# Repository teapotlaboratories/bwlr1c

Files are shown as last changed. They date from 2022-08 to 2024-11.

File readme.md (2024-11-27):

  
# Teapotlabs BWLR1C
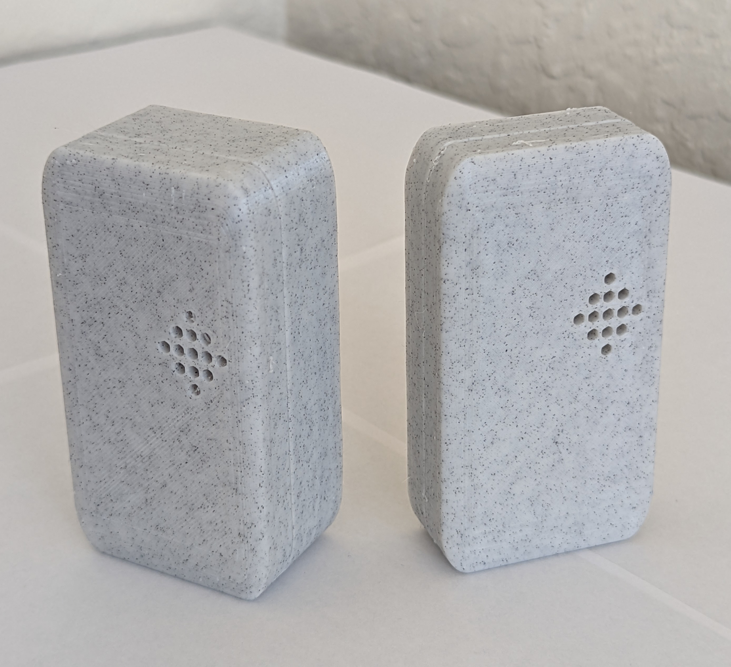
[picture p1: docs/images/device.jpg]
 
 
Teapotlabs BWLR1C is a wireless LoRa environmental sensor capable of sensing temperature, humidity, air pressure and air quality using the on-board BME680.
This device is an updated to **Teapotlabs BWLR1B,** by using the an on-board antenna.
By using an STM32WLE MCU, the device is capable of multi-year operation before changing the batteries

Teapotlabs BWLR1C is part of  [Teapot open-hardware project](https://github.com/teapotlaboratories).

## Sponsorship
Huge thanks to [PCBWay](https://www.pcbway.com/) to sponsored this project! Most of the project in Teapotlabs from PCB board, PCB Assembly, and 3D Printing is done through their rapid-prototyping services. The process from ordering to delivery of the device was really smooth and easy. We were really happy with the quality of the assembly and especially the customer support that was really easy to work with, where they help us identify and fix issue such as verifying BOM, checking components for assembly and even replacing damaged parts at no cost.

## Disclaimer
- The 1KM range is based on [AERQ - Air Quality Monitoring](https://www.seeedstudio.com/blog/2022/04/27/monitoring-indoor-air-pollutants-the-silent-issue-for-smart-city-iot-using-seeed-lora-e5-and-fusion-pcba/) design, but have not been tested on this device yet
- The position of the BME680 sensor on the board might not be the most efficient

## Future Works
- Change `SW4` wiring from GND to 3V3, to allow booting to STM32WLE USART Bootloader. This enable the user to flash the RAK3172 module using STM32CubeProgrammer without ST-Link.

## Specification

- [RAK3172](https://docs.rakwireless.com/Product-Categories/WisDuo/RAK3172-Module/Overview/): An STM32WLE5CC module
- 3.3V only power/pin. 
- 2uA Deep-Sleep
- BME680 for Environmental Sensing
- Switchable TX Power. 14 dBm(50mA) or 22 dBm(140mA) ( on 915MHz frequency )
- Supports LoRaWAN 1.0.3
- 1KM Range
- UART2 breakout for **Arduino** progamming
- SWD breakout for **Mbed OS/STM32Cube** programming
- SMA antenna connector
- **CR2450** battery holder *xor* **AA** battery holder
- Capacitor ( [optional to prolong CR2450 usage](https://www.rs-online.com/designspark/can-i-prolong-my-coin-cell-battery-life-with-a-capacitor) )

> Based-on [TI's White Paper](https://www.ti.com/lit/wp/swra349/swra349.pdf), using coin-cell to draw short high-power pulses (~40mA) is possible, but will reduce the effective capacity of the battery. The White Paper proposed a solution to increase the effective capacity
## Schematics

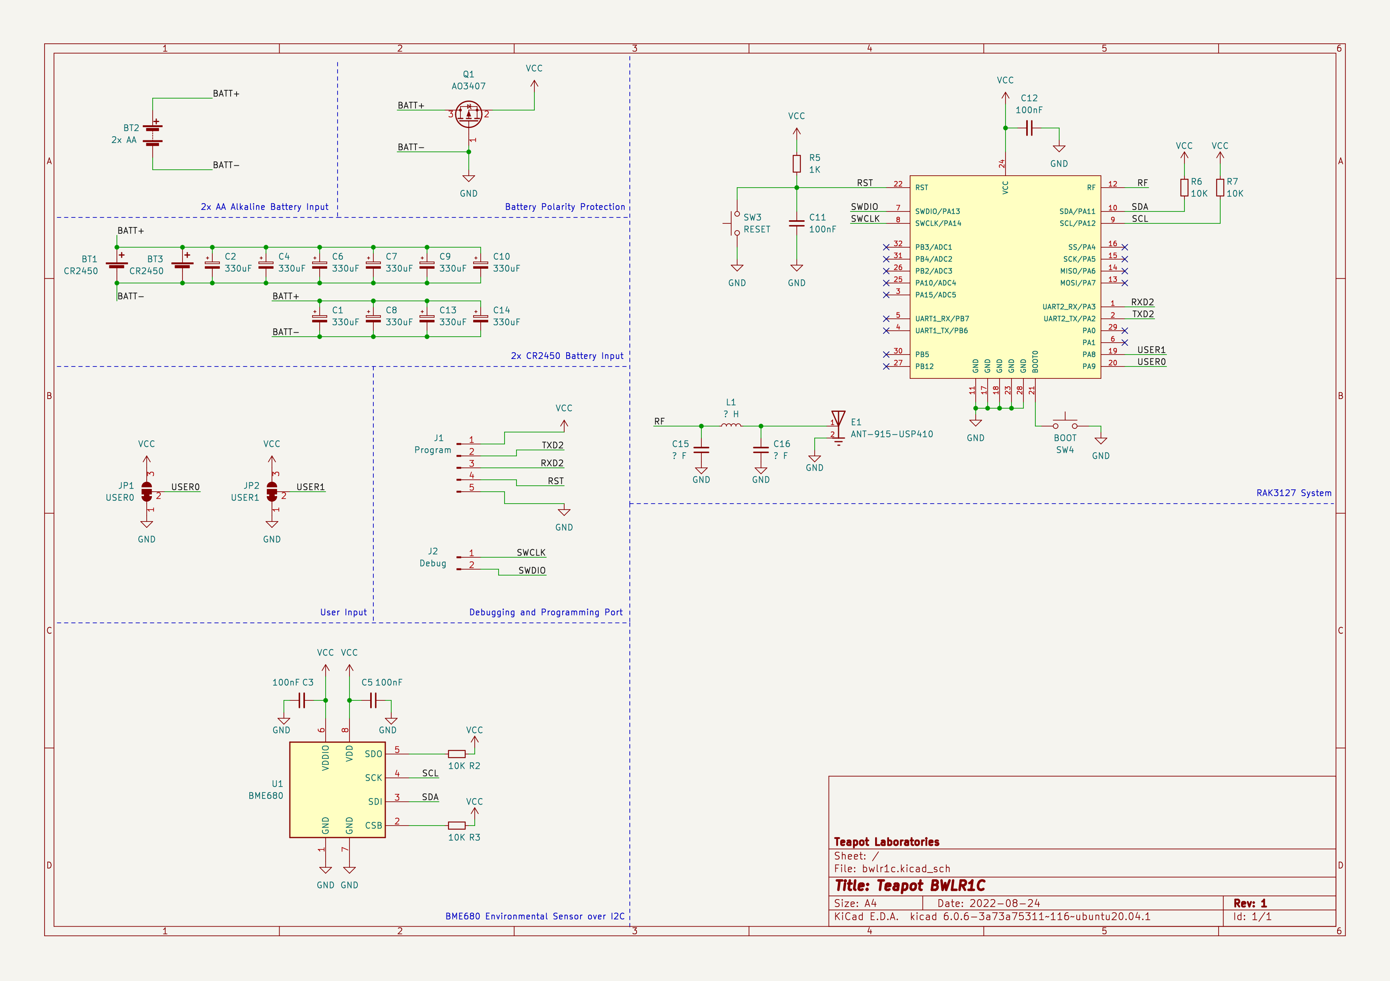
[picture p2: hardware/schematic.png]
schematic


## Boards
 <p align="center">  pcb_render<br><b>PCB Render</b></p>

Built using KiCAD, the board is design to be as small as possible when operated using CR2450 coin-cell batteries

| Top Board | Bottom Board |
|--|--|
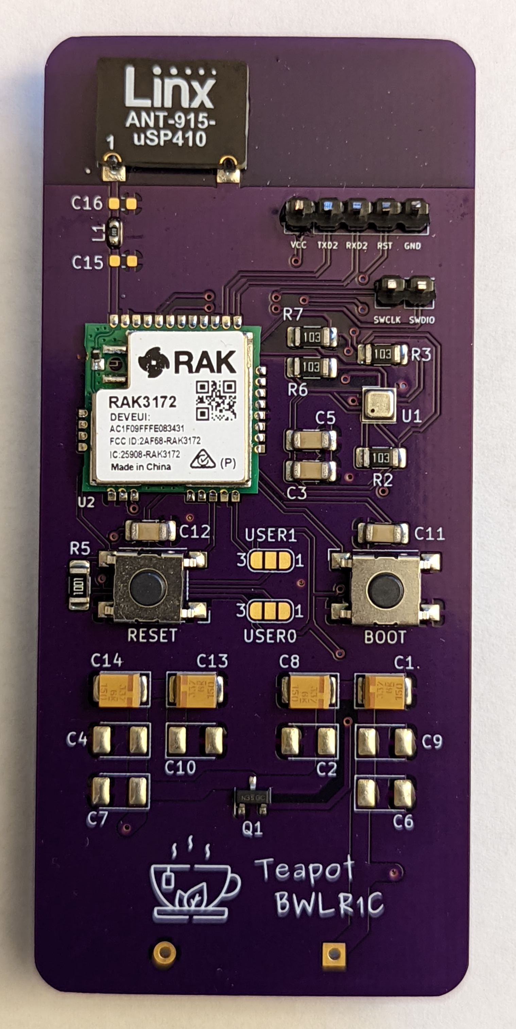
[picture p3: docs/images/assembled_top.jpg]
assembled_front
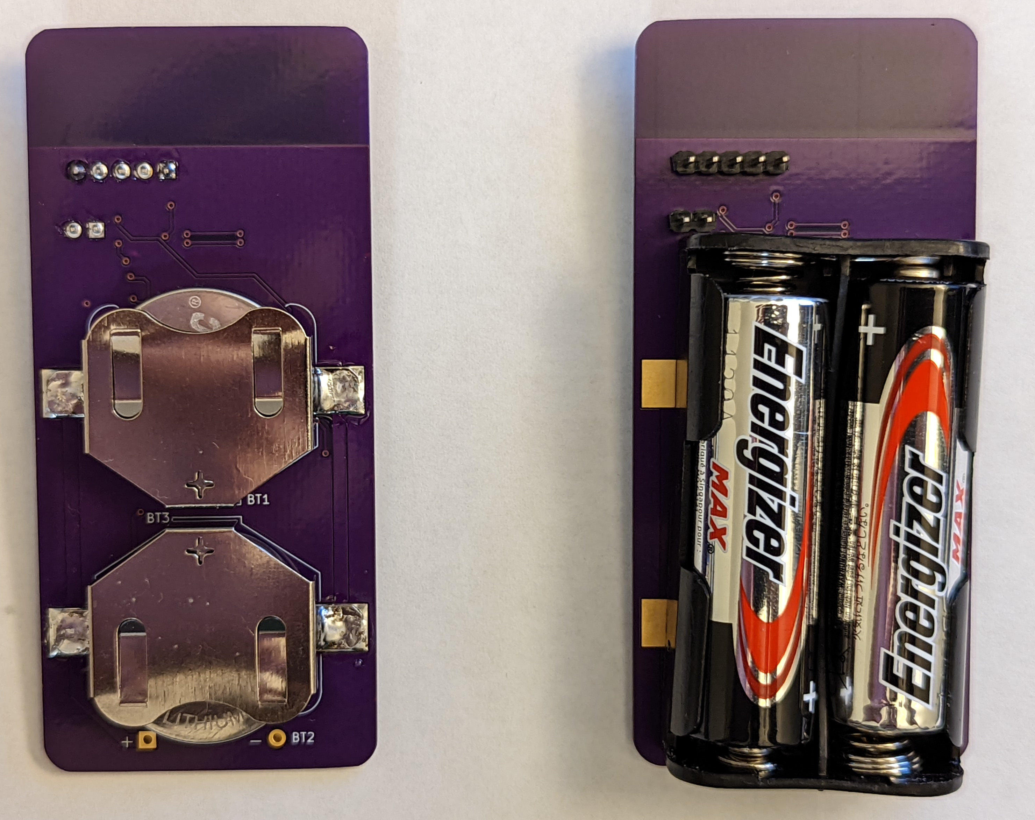
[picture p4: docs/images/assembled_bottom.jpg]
assembled_back
|  |  |
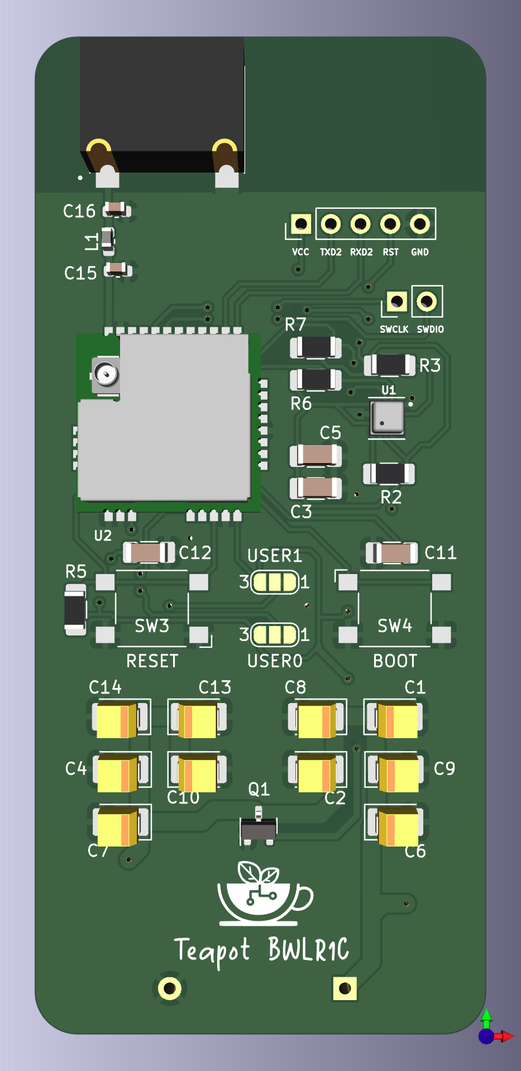
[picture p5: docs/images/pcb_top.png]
pcb_front
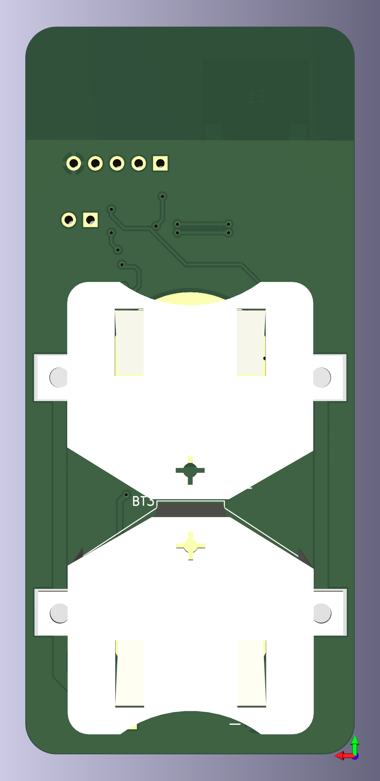
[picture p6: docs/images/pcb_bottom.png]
pcb_bottom
|  |  |

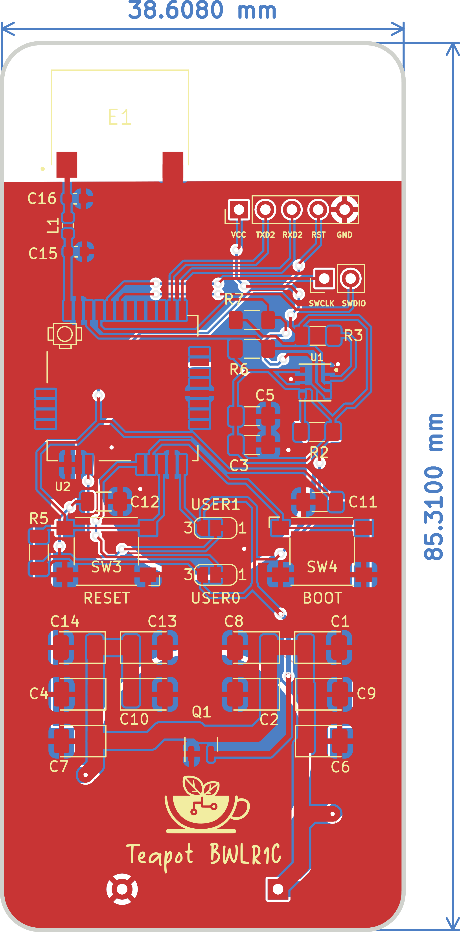
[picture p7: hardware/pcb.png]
pcb
 <p align="center"> <br><b>PCB Top and Bottom Layout</b></p> 
  
### Case
<p align="center">  case_render</p>

Built using [TinkerCAD](https://www.tinkercad.com), the cases are available for the CR2450 variant and the AA variant, 3D printable with any generic 3D printer with/without suppport (depends on the orientation). The STL files are available [here](https://github.com/teapotlaboratories/bwlr1c/tree/main/hardware/case)
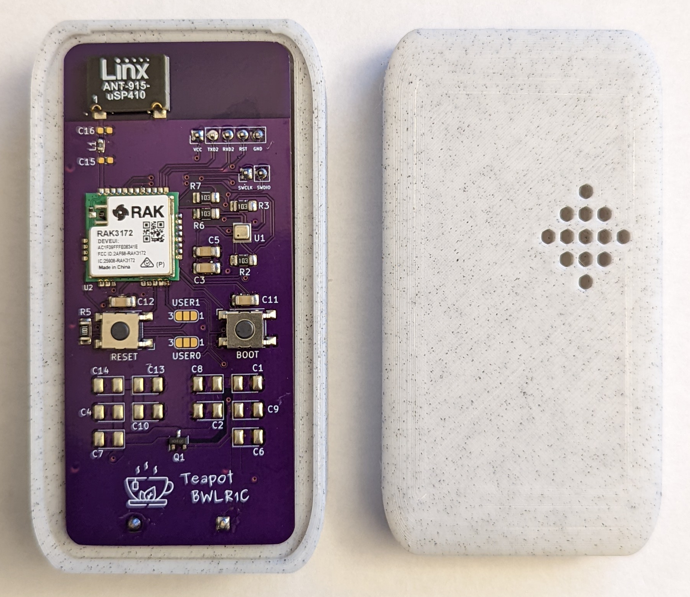
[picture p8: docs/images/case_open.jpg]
 <p align="center"><br><b>Case Open</b></p>

The case is design to be as small as possible with an additional magnets in the back to ease the placement of the sensor. The following are the list of material used at the time of testing:
- 4 piece of 8mm x 2mm neodymium magnet

<p align="center">placement_showcase<br><b>Sensor Placement with Magnet</b></p>

### Measurement
Power consumption and solar charging current are measured using [Nordic PPK2](https://www.nordicsemi.com/Products/Development-hardware/Power-Profiler-Kit-2).
The following are the summary of the measurement:
- Transmit 14dBm:  443ms @ 47mA
- Deep-Sleep : 2 uA

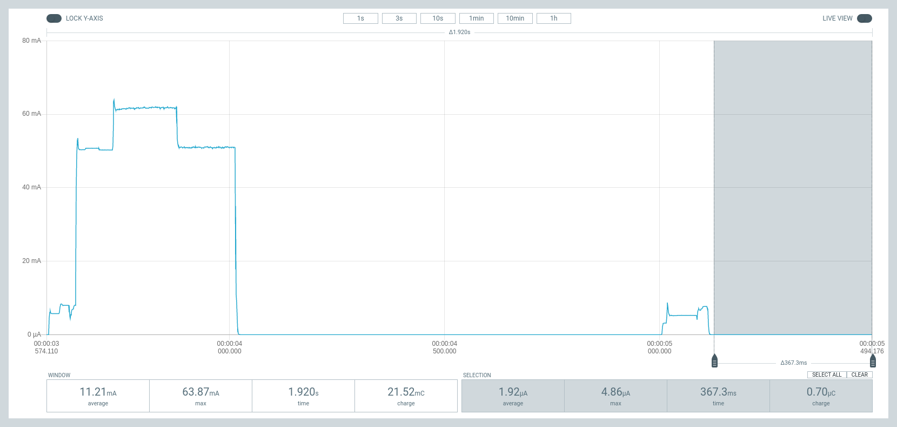
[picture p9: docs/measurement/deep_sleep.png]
deep_sleep
<p align="center"><br><b>Deep-Sleep</b></p>

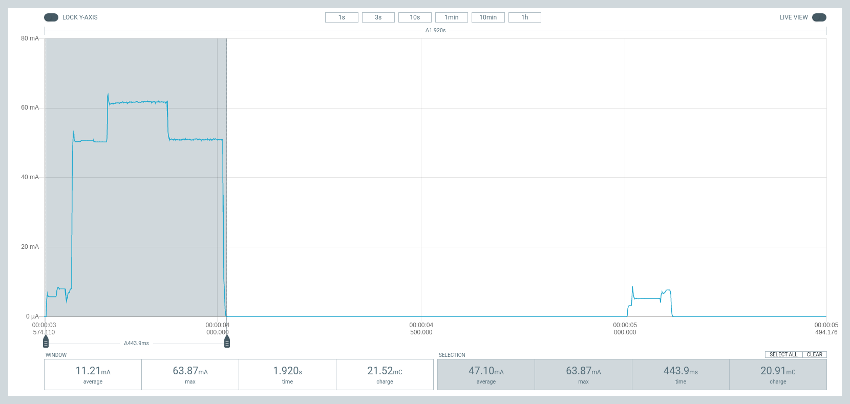
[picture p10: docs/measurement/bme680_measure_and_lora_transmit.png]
bme688_measure_and_lora_transmit
<p align="center"><br><b>BME688 Measure and LoRa Transmit</b></p>

More measurement can be found [here](https://github.com/teapotlaboratories/bwlr1c/tree/main/docs/measurement)

### Bill Of Materials
Most of the components are generic and can be bought from any electornics/semi-conductor distributor. RAK3172 is the only component available in [RAKwireless store](https://store.rakwireless.com/products/wisduo-lpwan-module-rak3172?variant=40014759493830). The bill of materials can be downloaded [here](https://github.com/teapotlaboratories/bwlr1c/raw/main/hardware/bill_of_materials.csv)

> :warning: **Be sure to buy the RAK3172 variant without IPEX to use the On-Board Antenna** 

|Id |Designator |Package |Quantity|Designation |Notes |
|---|---|---|---|---|---|
|1  |C5,C12,C11,C3 |C_1206_3216Metric |4 |100nF | |
|2  |SW4 |SW_SPST_Omron_B3FS-100xP |1 |BOOT | |
|3  |R7,R2,R3,R6 |R_1206_3216Metric |4 |10K | |
|4  |C9,C8,C10,C2,C4,C13,C14,C6,C1,C7|CP_EIA-3528-15_AVX-H |10 |330uF |Optional |
|5  |R5 |R_1206_3216Metric |1 |1K | |
|6  |E1 |XDCR_ANT-915-USP410 |1 |ANT-915-USP410| |
|7  |SW3 |SW_SPST_Omron_B3FS-100xP |1 |RESET | |
|8  |U1 |BME680-PSON80P300X300X100-8N |1 |BME680 | |
|9  |U2 |RAK3172 |1 |RAK3172 | |
|10 |Q1 |SOT-23 |1 |AO3407 | |
|11 |BT3,BT1 |BatteryHolder_Keystone_3008_1x2450|2 |CR2450 |Mutual Exclusive with BT2 |
|12 |BT2 |BatteryHolder_Keystone_2462_2xAA  |1 |2x AA |Mutual Exclusive with BT3 and BT1|

## Programming
Programming the device can be done over the **UART2** or **SWD**, available next to the On-board antenna.
Out of the factory, the RAK3172 chip ships with an **AT firmware** that can be tested by connecting a USB-to-UART bridge to the **UART2** port.

The following are some very good tutorial to start developing with the device:

- [Communicating with the AT firmware](https://docs.rakwireless.com/Product-Categories/WisDuo/RAK3172-Module/Quickstart/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)
 - [Programming with Arduino](https://docs.rakwireless.com/Product-Categories/WisDuo/RAK3172-Module/Quickstart/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)
 - [Programming with STM32Cube](https://docs.rakwireless.com/Product-Categories/WisDuo/RAK3172-Module/Low-Level-Development/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)
 - [Programming with MbedOS](https://github.com/hallard/LoRa-E5-Tiny/blob/main/README.md#compile-and-flash-firmware)

For connecting to the **UART2** port, use any USB-to-UART bridge module. In testing, the [Sparkfun](https://www.sparkfun.com/products/14050) board is used for communication with AT firmware and programming over **Arduino**.
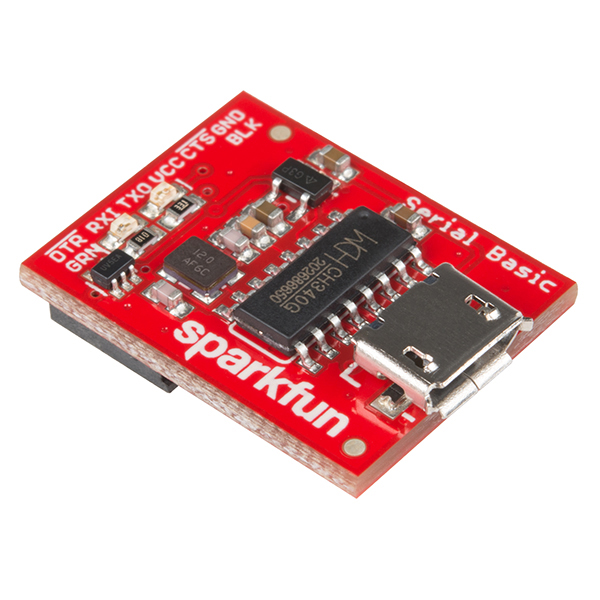
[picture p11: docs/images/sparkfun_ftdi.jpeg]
 <p align="center"> <br>Sparkfun USB-to-UART Bridge</p>

> :warning: **Be sure to only use 3.3V module. Do not 5V module** 

For connecting to the **SWD** port, use ST-Link v2  in-circuit debugger and programmer from STM. In testing, ST-Link v2 clone will not work. The ST-Link v2 should atleast be reconizeable by the [STM32CubeProgrammer](https://www.st.com/en/development-tools/stm32cubeprog.html).
A cheap and alternative way to get an authorized ST-Link is to buy a Nucleo board, cut the top part which contain the ST-Link and use it as an external programmer.
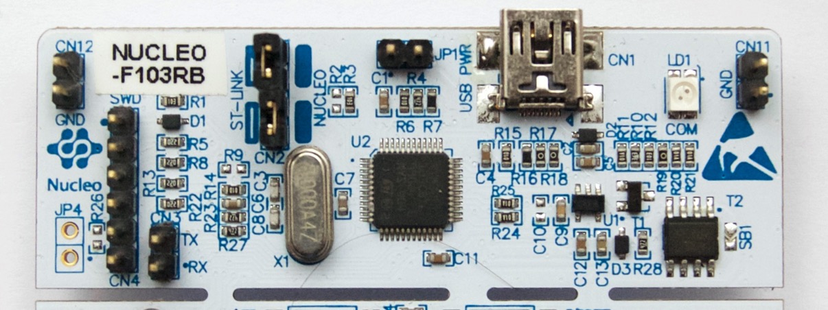
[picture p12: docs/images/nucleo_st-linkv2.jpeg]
 <p align="center"> <br>ST-Link v2 from a Nucleo Development Board</p>
Here are some good tutorial to convert a Nucleo to and external ST-Link v2:

 - https://www.radioshuttle.de/en/turtle-en/nucleo-st-link-interface-en/
 - https://jeelabs.org/book/1547a/index.html

## Notes
There are some issue, notes, and behavior that was discovered at the time of testing and development. The following are those discovery:
- Using Arduino RUI3 framework may introduce some-instability after programming. It is observed that by randomly power-cycling the board in-short interval after flashing, causes the board to hang in Boot mode. The fix is currently on the works.

## Reference
The project won't be possible without the amazing work from people across the globe. The following are the reference to those awesome projects:

 - [LoRa e5 Tiny](https://github.com/hallard/LoRa-E5-Tiny)
 - [AERQ - Air Quality Monitoring](https://www.seeedstudio.com/blog/2022/04/27/monitoring-indoor-air-pollutants-the-silent-issue-for-smart-city-iot-using-seeed-lora-e5-and-fusion-pcba/)

## License
The product is open-source! However, some part of library used under **src**, might have it's own license.
Please reach out or create a ticket to report any license violation.



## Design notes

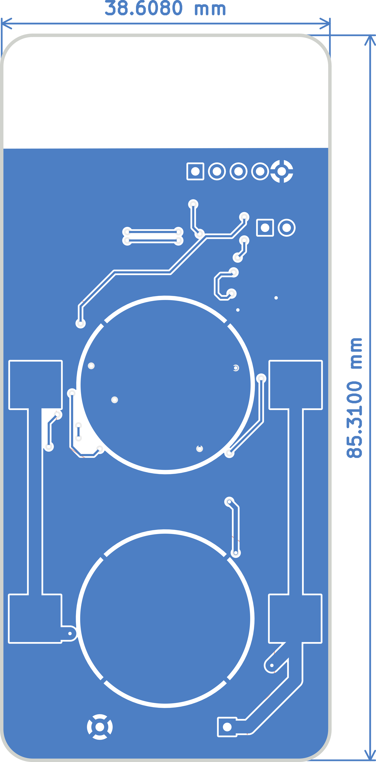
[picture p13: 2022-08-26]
hardware/pcb_bottom.png

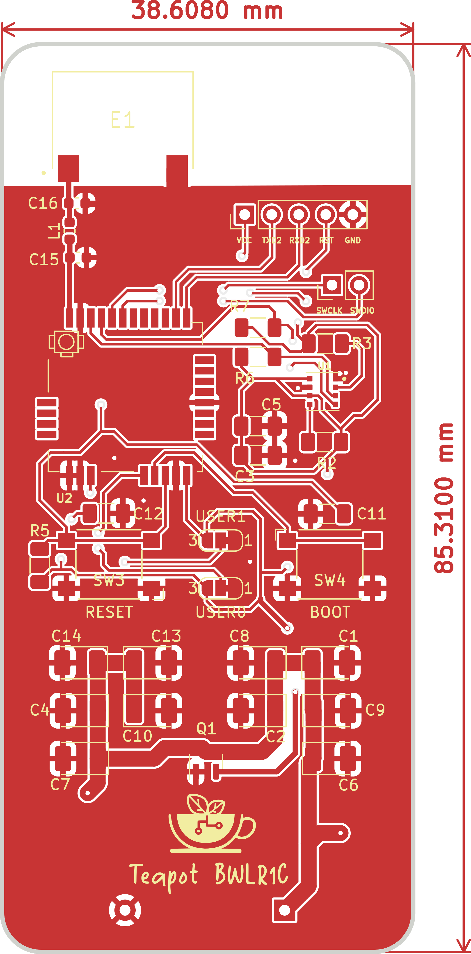
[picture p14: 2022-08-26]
hardware/pcb_top.png

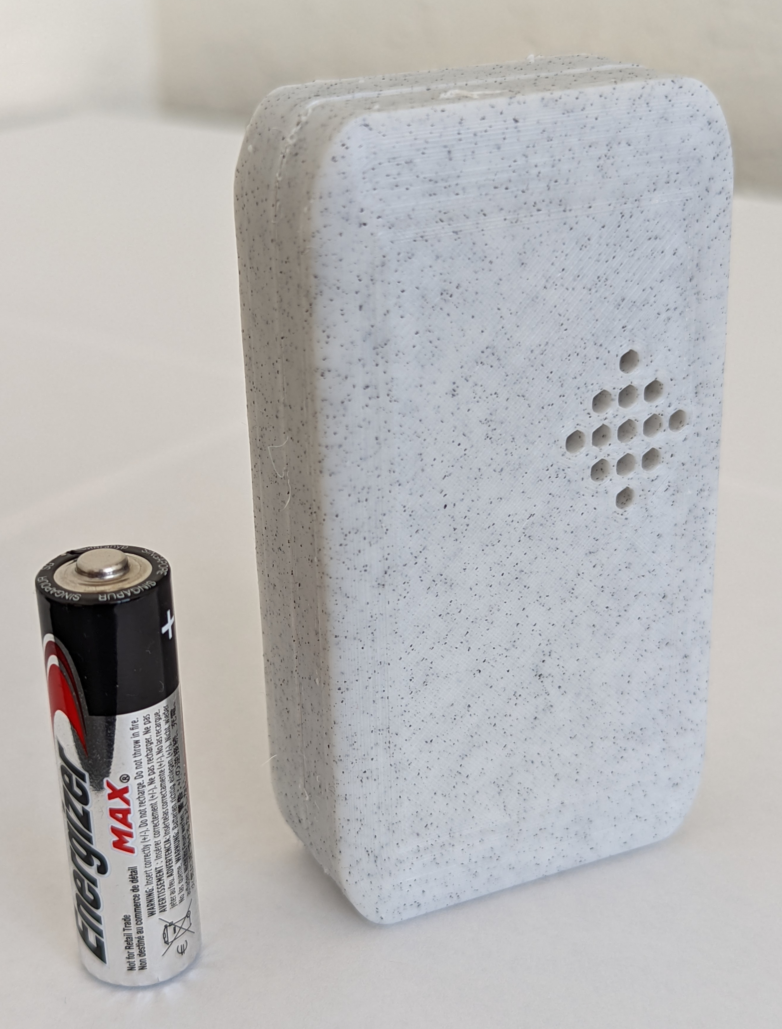
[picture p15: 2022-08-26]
docs/images/standing_with_aa_for_comparison.jpg

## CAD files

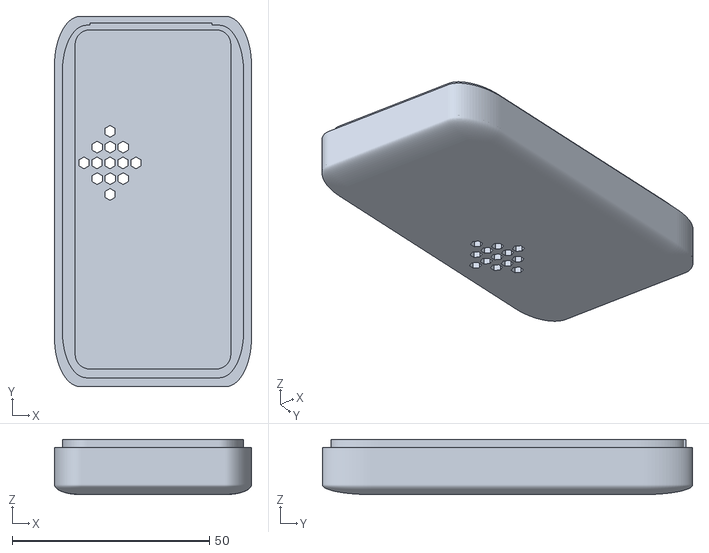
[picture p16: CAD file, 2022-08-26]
hardware/case/top.stl
50.0 x 94.0 x 14.0

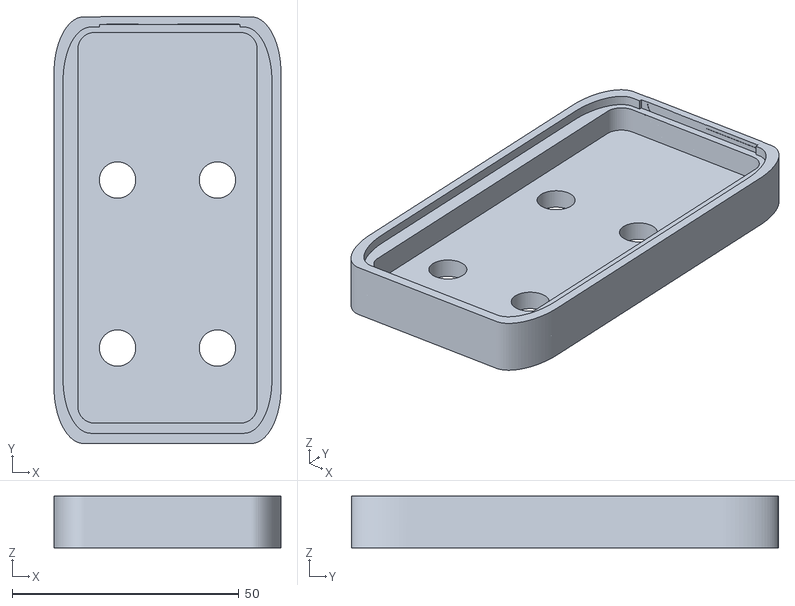
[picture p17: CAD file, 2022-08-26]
hardware/case/cr2450_bottom_with_magnet.stl
50.0 x 94.1 x 11.4

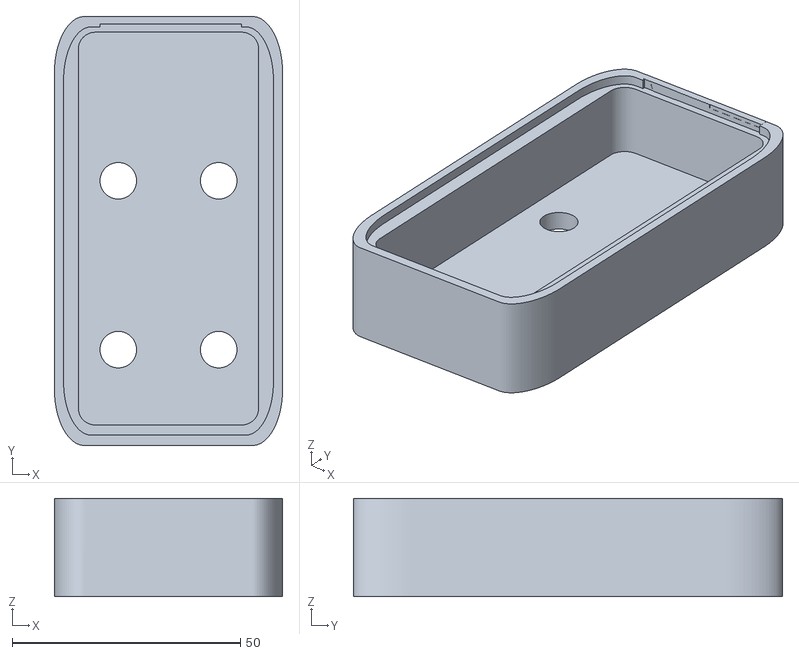
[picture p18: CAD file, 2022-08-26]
hardware/case/aa_bottom_with_magnet.stl
50.0 x 94.0 x 21.5

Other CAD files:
hardware/case/cr2450_bottom.stl
hardware/case/aa_bottom.stl

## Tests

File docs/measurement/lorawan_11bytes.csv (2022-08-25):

Timestamp(ms) | Current(uA)
0 | 1.434
1 | 1.423
2 | 1.426
3 | 1.432
4 | 1.440
5 | 1.434
6 | 1.441
7 | 1.432
8 | 1.426
9 | 1.424
10 | 1.418
11 | 1.418
12 | 1.422
13 | 1.439
14 | 1.429
15 | 1.414
16 | 1.423
17 | 1.429
18 | 1.422
19 | 1.412
20 | 1.426
21 | 1.423
22 | 1.431
23 | 1.438
24 | 1.435
25 | 1.434
26 | 1.430
27 | 1.427
28 | 1.418
29 | 1.428
30 | 1.434
31 | 1.431
32 | 1.433
33 | 1.432
34 | 1.432
35 | 1.429
36 | 1.421
37 | 1.424
38 | 1.436
39 | 1.443
40 | 1.432
41 | 1.419
42 | 1.416
43 | 1.419
44 | 1.420
45 | 1.423
46 | 1.441
47 | 1.443
48 | 1.430
49 | 1.420
50 | 1.417
51 | 1.417
52 | 1.420
53 | 1.439
54 | 1.429
55 | 1.432
56 | 1.435
57 | 1.432
58 | 1.421
59 | 1.420
60 | 1.422
61 | 1.430
62 | 1.429
63 | 1.430
64 | 1.422
65 | 1.430
66 | 1.428
67 | 1.434
68 | 1.427
69 | 1.423
70 | 1.415
71 | 1.404
72 | 1.414
73 | 1.424
74 | 1.431
75 | 1.457
76 | 1.471
77 | 1.481
78 | 1.471
79 | 1.473
80 | 1.462
81 | 1.457
82 | 1.457
83 | 1.448
84 | 1.458
85 | 1.449
86 | 1.440
87 | 1.441
88 | 1.440
89 | 1.434
90 | 1.431
91 | 1.420
92 | 1.433
93 | 1.446
94 | 1.442
95 | 1.450
96 | 1.444
97 | 1.444
98 | 1.455
99 | 1.440
100 | 1.443
101 | 1.439
102 | 1.433
103 | 1.429
104 | 1.436
105 | 1.428
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

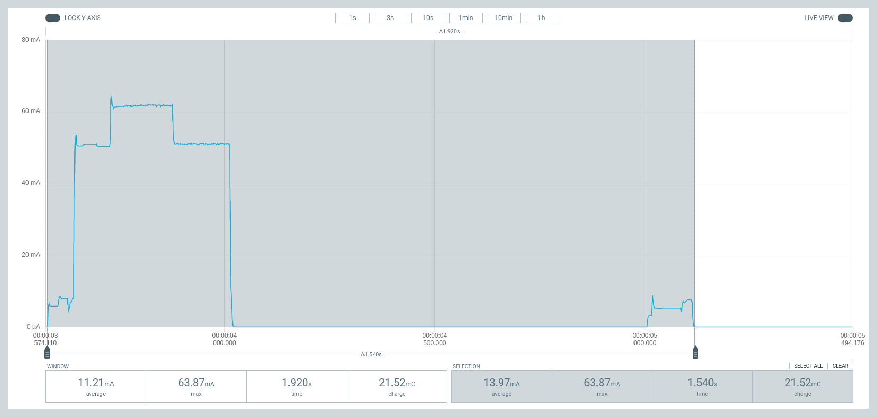
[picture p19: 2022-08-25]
docs/measurement/active.png

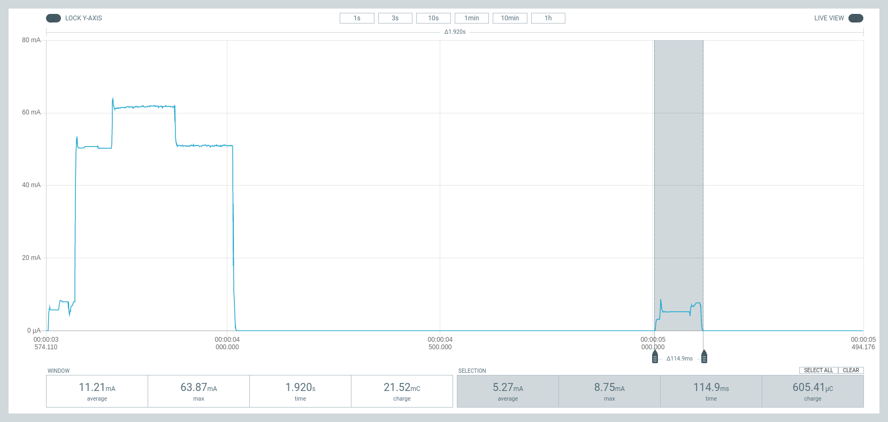
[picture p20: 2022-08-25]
docs/measurement/lora_ack.png

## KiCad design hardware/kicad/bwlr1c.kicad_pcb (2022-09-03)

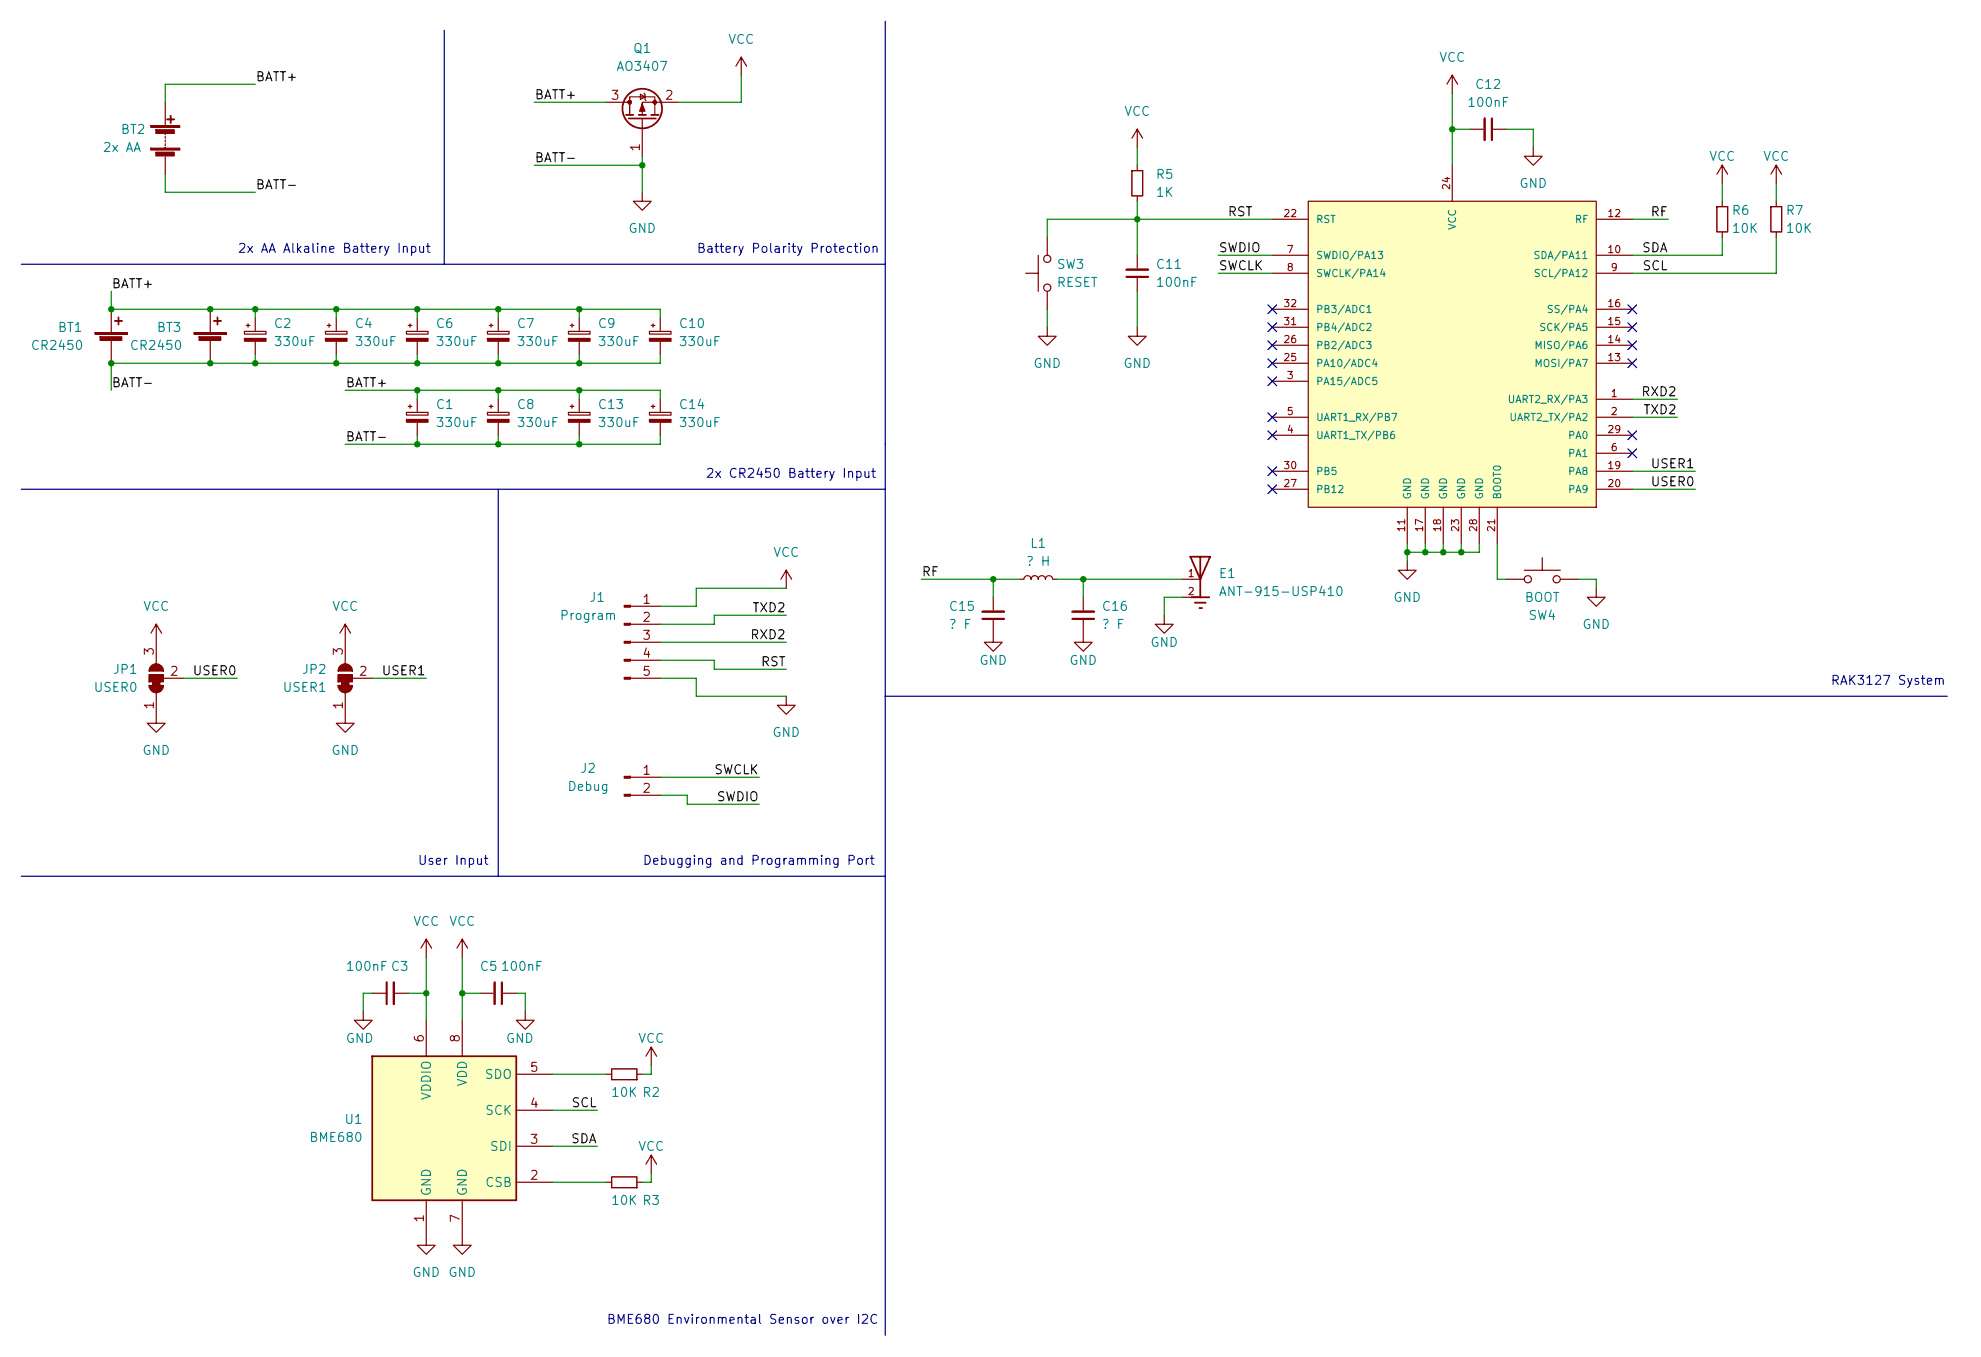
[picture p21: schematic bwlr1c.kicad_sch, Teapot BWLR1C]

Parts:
BT1, BT3: CR2450; BatteryHolder_Keystone_3008_1x2450
BT2: 2x AA; BatteryHolder_Keystone_2462_2xAA
C1, C2, C4, C6, C7, C8, C9, C10, C13, C14: 330uF; CP_EIA-3528-15_AVX-H_Pad1.50x2.35mm_HandSolder
C3, C5, C11, C12: 100nF; C_1206_3216Metric_Pad1.33x1.80mm_HandSolder
C15, C16: ? F; C_0603_1608Metric
E1: ANT-915-USP410; XDCR_ANT-915-USP410; PARTREV N/A
J1: Program; PinHeader_1x05_P2.54mm_Vertical
J2: Debug; PinHeader_1x02_P2.54mm_Vertical
JP1: USER0; SolderJumper-3_P1.3mm_Bridged12_RoundedPad1.0x1.5mm_NumberL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
JP2: USER1; SolderJumper-3_P1.3mm_Bridged12_RoundedPad1.0x1.5mm_NumberL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
L1: ? H; L_0603_1608Metric
Q1: AO3407; SOT-23
R2, R3, R6, R7: 10K; R_1206_3216Metric_Pad1.30x1.75mm_HandSolder
R5: 1K; R_1206_3216Metric_Pad1.30x1.75mm_HandSolder
SW3: RESET; SW_SPST_Omron_B3FS-100xP
SW4: BOOT; SW_SPST_Omron_B3FS-100xP
U1: BME680; BME680-PSON80P300X300X100-8N
U2: RAK3172

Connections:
/BATT+: BT1.1 (+), BT2.1 (+), BT3.1 (+), C1.1, C2.1, C4.1, C6.1, C7.1, C8.1, C9.1, C10.1, C13.1, C14.1, Q1.3 (D)
/RF: C15.2, L1.1, U2.12 (RF)
/RST: C11.2, J1.4, R5.2, SW3.2, U2.22 (RST)
/RXD2: J1.3, U2.1 (UART2_RX/PA3)
/SCL: R7.2, U1.4 (SCK), U2.9 (SCL/PA12)
/SDA: R6.2, U1.3 (SDI), U2.10 (SDA/PA11)
/SWCLK: J2.1, U2.8 (SWCLK/PA14)
/SWDIO: J2.2, U2.7 (SWDIO/PA13)
/TXD2: J1.2, U2.2 (UART2_TX/PA2)
/USER0: JP1.2 (C), U2.20 (PA9)
/USER1: JP2.2 (C), U2.19 (PA8)
GND: BT1.2 (-), BT2.2 (-), BT3.2 (-), C1.2, C2.2, C3.1, C4.2, C5.1, C6.2, C7.2, C8.2, C9.2, C10.2, C11.1, C12.1, C13.2, C14.2, C15.1, C16.1, E1.2, J1.5, JP1.1 (A), JP2.1 (A), Q1.1 (G), SW3.1, SW4.2, U1.1 (GND), U1.7 (GND), U2.11 (GND), U2.17 (GND), U2.18 (GND), U2.23 (GND), U2.28 (GND)
unnamed: C16.2, E1.1, L1.2
unnamed: R2.2, U1.5 (SDO)
unnamed: R3.2, U1.2 (CSB)
unnamed: SW4.1, U2.21 (BOOT0)
VCC: C3.2, C5.2, C12.2, J1.1, JP1.3 (B), JP2.3 (B), Q1.2 (S), R2.1, R3.1, R5.1, R6.1, R7.1, U1.6 (VDDIO), U1.8 (VDD), U2.24 (VCC)

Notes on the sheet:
RAK3127 System
BME680 Environmental Sensor over I2C
2x CR2450 Battery Input
Battery Polarity Protection
2x AA Alkaline Battery Input
User Input
Debugging and Programming Port

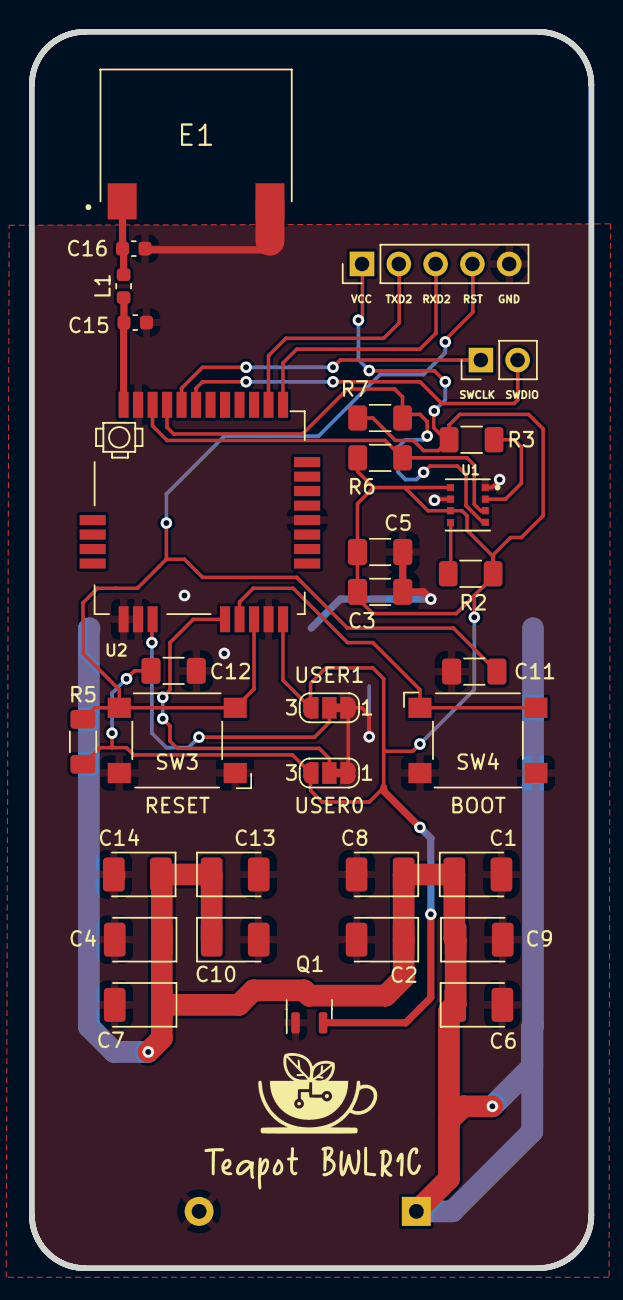
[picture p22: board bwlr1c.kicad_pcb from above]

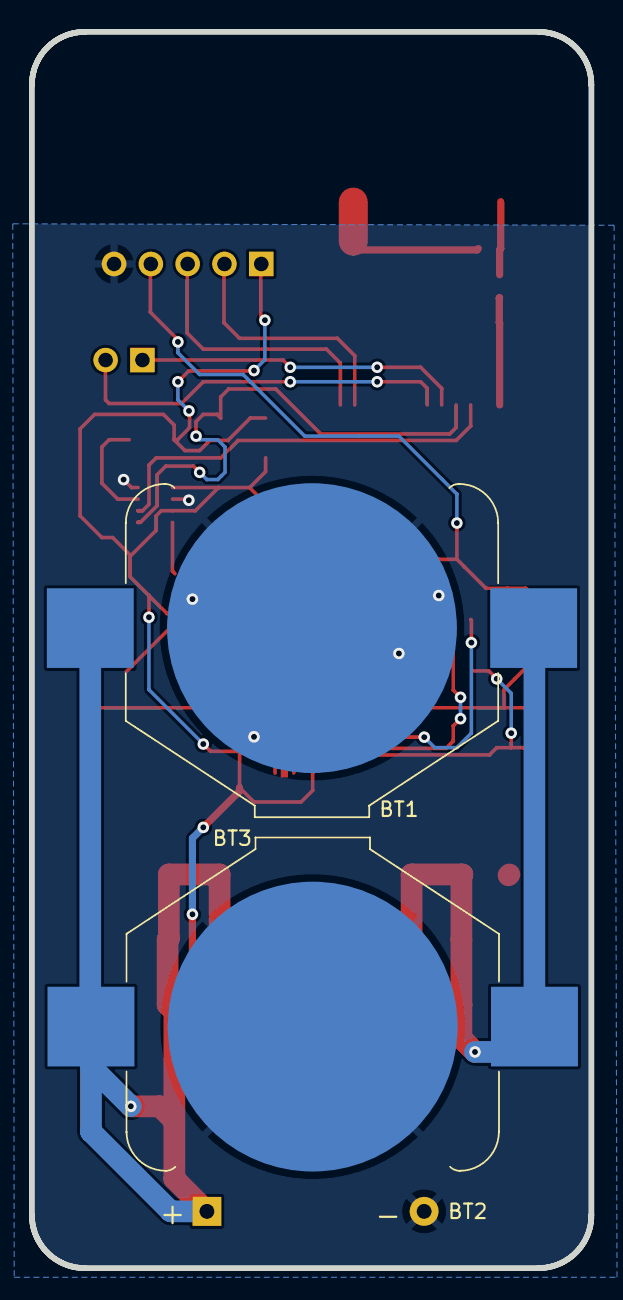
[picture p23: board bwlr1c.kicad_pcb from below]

Board: 2 copper layers, 38.6 x 85.3 mm, 35 parts (3 on the bottom side), 17 nets.

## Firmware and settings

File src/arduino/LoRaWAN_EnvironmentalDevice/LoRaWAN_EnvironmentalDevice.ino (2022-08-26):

#include<CayenneLPP.h>
#include "Zanshin_BME680.h"  // Include the BME680 Sensor library

#define OTAA_DEVEUI   {0xac, 0x1f, 0x09, 0xff, 0xfe, 0x08, 0x33, 0x7f}
#define OTAA_APPKEY   {0xb5, 0x12, 0xfb, 0x72, 0xfc, 0x87, 0x20, 0x2a, 0xb3, 0x90, 0xc1, 0xbe, 0x8e, 0x46, 0x99, 0xf6}
#define OTAA_APPEUI   {0x0E, 0x0D, 0x0D, 0x01, 0x0E, 0x01, 0x02, 0x0E}
#define OTAA_PERIOD   (600*1000) // 10 minute seconds
#define OTAA_BAND     (RAK_REGION_US915)
#define TXP 14        // FCC limits TX power to 14 dBM

#define TRY_SEND_REQUEST 20 // try calling api.lorawan.send()

BME680_Class BME680;  ///< Create an instance of the BME680 class

/** Packet buffer for sending */
CayenneLPP payload(32);

void recvCallback(SERVICE_LORA_RECEIVE_T * data)
{
  if (data->BufferSize > 0) {
    Serial.println("Something received!");
    for (int i = 0; i < data->BufferSize; i++) {
      Serial.printf("%x", data->Buffer[i]);
    }
    Serial.print("\r\n");
  }
}

void joinCallback(int32_t status)
{
  Serial.printf("Join status: %d\r\n", status);
}

void sendCallback(int32_t status)
{
  if (status == 0) {
    Serial.println("Successfully sent");
  } else {
    Serial.println("Sending failed");
  }
}


void setup()
{
  Serial.begin(115200, RAK_AT_MODE);

  Serial.println("RAKwireless LoRaWan OTAA Example");
  Serial.println("------------------------------------------------------");

  // OTAA Device EUI MSB first
  uint8_t node_device_eui[8] = OTAA_DEVEUI;
  // OTAA Application EUI MSB first
  uint8_t node_app_eui[8] = OTAA_APPEUI;
  // OTAA Application Key MSB first
  uint8_t node_app_key[16] = OTAA_APPKEY;

  if (!api.lorawan.appeui.set(node_app_eui, 8)) {
    Serial.printf("LoRaWan OTAA - set application EUI is incorrect! \r\n");
    return;
  }
  if (!api.lorawan.appkey.set(node_app_key, 16)) {
    Serial.printf("LoRaWan OTAA - set application key is incorrect! \r\n");
    return;
  }
  if (!api.lorawan.deui.set(node_device_eui, 8)) {
    Serial.printf("LoRaWan OTAA - set device EUI is incorrect! \r\n");
    return;
  }

  if (!api.lorawan.band.set(OTAA_BAND)) {
    Serial.printf("LoRaWan OTAA - set band is incorrect! \r\n");
    return;
  }
  
  if (!api.lorawan.deviceClass.set(RAK_LORA_CLASS_A)) {
    Serial.printf("LoRaWan OTAA - set device class is incorrect! \r\n");
    return;
  }
  if (!api.lorawan.njm.set(RAK_LORA_OTAA))  // Set the network join mode to OTAA
  {
    Serial.printf
  ("LoRaWan OTAA - set network join mode is incorrect! \r\n");
    return;
  }
  if (!api.lorawan.join())  // Join to Gateway
  {
    Serial.printf("LoRaWan OTAA - join fail! \r\n");
    return;
  }

  /** Wait for Join success */
  while (api.lorawan.njs.get() == 0) {
    Serial.print("Wait for LoRaWAN join...");
    api.lorawan.join();
    delay(10000);
  }

  if (!api.lorawan.adr.set(true)) {
    Serial.printf
  ("LoRaWan OTAA - set adaptive data rate is incorrect! \r\n");
    return;
  }
  if (!api.lorawan.rety.set(2)) {
    Serial.printf("LoRaWan OTAA - set retry times is incorrect! \r\n");
    return;
  }
  if (!api.lorawan.cfm.set(1)) {
    Serial.printf("LoRaWan OTAA - set confirm mode is incorrect! \r\n");
    return;
  }
  
  if (!api.lorawan.txp.set(TXP)) {
    Serial.printf("LoRaWan TXP - set transmit power fail! \r\n");
    return;
  }
//  
//  if (!api.lorawan.pnm.set(false)) {
//    Serial.printf("LoRaWan OTAA - set to private network fail! \r\n");
//    return;
//  };

  /** Check LoRaWan Status*/
  Serial.printf("Duty cycle is %s\r\n", api.lorawan.dcs.get()? "ON" : "OFF"); // Check Duty Cycle status
  Serial.printf("Packet is %s\r\n", api.lorawan.cfm.get()? "CONFIRMED" : "UNCONFIRMED");  // Check Confirm status
  uint8_t assigned_dev_addr[4] = { 0 };
  api.lorawan.daddr.get(assigned_dev_addr, 4);
  Serial.printf("Device Address is %02X%02X%02X%02X\r\n", assigned_dev_addr[0], assigned_dev_addr[1], assigned_dev_addr[2], assigned_dev_addr[3]);  // Check Device Address
  Serial.printf("Uplink period is %ums\r\n", OTAA_PERIOD);
  Serial.println("");
  api.lorawan.registerRecvCallback(recvCallback);
  api.lorawan.registerJoinCallback(joinCallback);
  api.lorawan.registerSendCallback(sendCallback);

  /** Setup BME680 **/
  
  Serial.print(F("- Initializing BME680 sensor\n"));
  while (!BME680.begin(I2C_STANDARD_MODE)) {  // Start BME680 using I2C, use first device found
    Serial.print(F("-  Unable to find BME680. Trying again in 5 seconds.\n"));
    delay(5000);
  }  // of loop until device is located
  Serial.print(F("- Setting 16x oversampling for all sensors\n"));
  BME680.setOversampling(TemperatureSensor, Oversample16);  // Use enumerated type values
  BME680.setOversampling(HumiditySensor, Oversample16);     // Use enumerated type values
  BME680.setOversampling(PressureSensor, Oversample16);     // Use enumerated type values
  Serial.print(F("- Setting IIR filter to a value of 4 samples\n"));
  BME680.setIIRFilter(IIR4);  // Use enumerated type values
  Serial.print(F("- Setting gas measurement to 320\xC2\xB0\x43 for 150ms\n"));  // "�C" symbols
  BME680.setGas(320, 150);  // 320�c for 150 milliseconds
}

void uplink_routine()
{
  static int32_t  temp, humidity, pressure, gas;  // BME readings
  BME680.getSensorData(temp, humidity, pressure, gas);  // Get readings
  static float batt = api.system.bat.get(); // use api system for example, does not actually works!

  payload.reset();
  payload.addTemperature(1, ((float) temp) / 100);
  payload.addRelativeHumidity(2, ((float) humidity) / 1000);
  payload.addBarometricPressure(3, ((float) pressure) / 100);
  payload.addGenericSensor(4, ((float) gas) / 100);
  payload.addVoltage(5, batt);
  

  Serial.printf("Data Packet: %d\n", payload.getSize());
  Serial.printf("Temperature: %f\n", ((float) temp) / 100);
  Serial.printf("Battery: %f\n", batt);

  /** Send the data package */
  uint8_t try_send_request = TRY_SEND_REQUEST;
  while( !api.lorawan.send(payload.getSize(), (uint8_t *) payload.getBuffer(), 1) && try_send_request--) {
   Serial.println("Retry sending payload again");
   delay(1000);
  }
  
  if (!try_send_request){  
    Serial.println("Sending is fail");
  } else { 
    Serial.println("Sending is requested"); 
  }
}

void loop()
{
  if (!api.lorawan.txp.set(TXP)) {
    Serial.printf("LoRaWan TXP - set transmit power fail! \r\n");
    return;
  }
  int retry = 3;
  /** Wait for Join success */
  while (api.lorawan.njs.get() == 0) {
    Serial.print("Wait for LoRaWAN join...");
    api.lorawan.join();
    api.system.sleep.all(10000);
    if (retry-- <= 0) {
      break;
    }    
  }

  if(retry > 0 ){
    uplink_routine();
  }
  Serial.printf("Try sleep %ums..", OTAA_PERIOD);
  api.system.sleep.all(OTAA_PERIOD);
  Serial.println("Wakeup..");
  
}

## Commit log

2022-08-26 upload resources
    [aa_bottom.stl, aa_bottom_with_magnet.stl, bill_of_materials.csv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]
2022-09-03 update footprint and library
    [bwlr1c.kicad_pcb]

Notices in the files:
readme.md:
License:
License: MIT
